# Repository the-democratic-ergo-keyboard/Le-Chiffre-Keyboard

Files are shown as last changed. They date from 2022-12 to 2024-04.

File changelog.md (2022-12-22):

Changelog:

Sadek Baroudi: 2022-12-15
-------------------------------
removed leftover decoupling capactiors, no longer needed
removed one of the shift registers
added two thumbs in the center
changed 2U to 1U and shifted keys inwards
redid routing so that front side is vertical, and backside is horizontal
fixed schematic
	* elite-c / nice nano
	* shift register
	* removed all the extra stuff that's no longer on the pcb
redid the switch matrix to use less cols to support the single shift register, and maximized gpio
added jlcpcb pcba support
other general cleanup...

Dasky: 2022-12-22
-------------------------------
add led power selection jumper raw/vcc
add led power switch circuit
added per key rgb
replaced ws2812b underglow with sk6803 mini-e
rotated all switches
rerouted pcb
add .gitignore
clean up backup files

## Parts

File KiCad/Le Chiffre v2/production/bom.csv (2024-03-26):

Designator | Footprint | Quantity | Value | LCSC Part #
D1, D10, D11, D12, D13, D14, D15, D16, D17, D18, D19, D2, D20, D21, D22, D23, D24, D25, D26, D27, D28, D29, D3, D30, D31, D32, D33, D34, D35, D36, D37, D4, D5, D6, D7, D8, D9 | D_SOD123 | 37 | 1N4148 | C909967
D38, D39, D40, D41, D42, D43, D44, D45, D46, D47, D48, D49, D50, D51, D52, D53, D54, D55, D56, D57, D58, D59, D60, D61, D62, D63, D64, D65, D66, D67, D68, D69, D70, D71, D72, D73, D74, D75, D76, D77, D78, D79, D80, D81, D82, D83, D84 | SK6803-MINI-E | 47 | SK6803_MINI-E | C5242955
H1 | TPSensorModule | 1 | MountingHole
J1 | PinHeader_1x06_P2.54mm_Vertical | 1 | Conn_01x06_Socket
J2 | PinSocket_1x04_P2.54mm_Vertical | 1 | Conn_01x04_Female
J3 | vik-keyboard-connector-horizontal | 1 | ~ | C479750
JP1 | SolderJumper-3_P1.3mm_Open_RoundedPad1.0x1.5mm | 1 | SolderJumper_3_Open
JP2 | SolderJumper-3_P1.3mm_Open_RoundedPad1.0x1.5mm | 1 | Jumper_3_Open
R7, R8 | R_0805 | 2 | 4.7k | C269746
SW1 | SW_SPST_TL3342 | 1 | SW_Push
SW10, SW11, SW12, SW13, SW14, SW15, SW16, SW17, SW18, SW19, SW2, SW20, SW21, SW22, SW23, SW24, SW25, SW26, SW27, SW28, SW29, SW3, SW30, SW31, SW32, SW33, SW34, SW35, SW37, SW38, SW39, SW4, SW5, SW6, SW7, SW8, SW9 | MX-Alps-Choc-1U-NoLED | 37 | SW_Push
SW36 | RotaryEncoder_Alps_EC12E-Switch_Vertical_H20mm_CircularMountingHoles | 1 | Rotary_Encoder_Switch
U1 | pro-micro-controller | 1 | pro-micro-controller
U2 | SOIC-16_3.9x9.9mm_P1.27mm | 1 | SN74HC595 | C94270

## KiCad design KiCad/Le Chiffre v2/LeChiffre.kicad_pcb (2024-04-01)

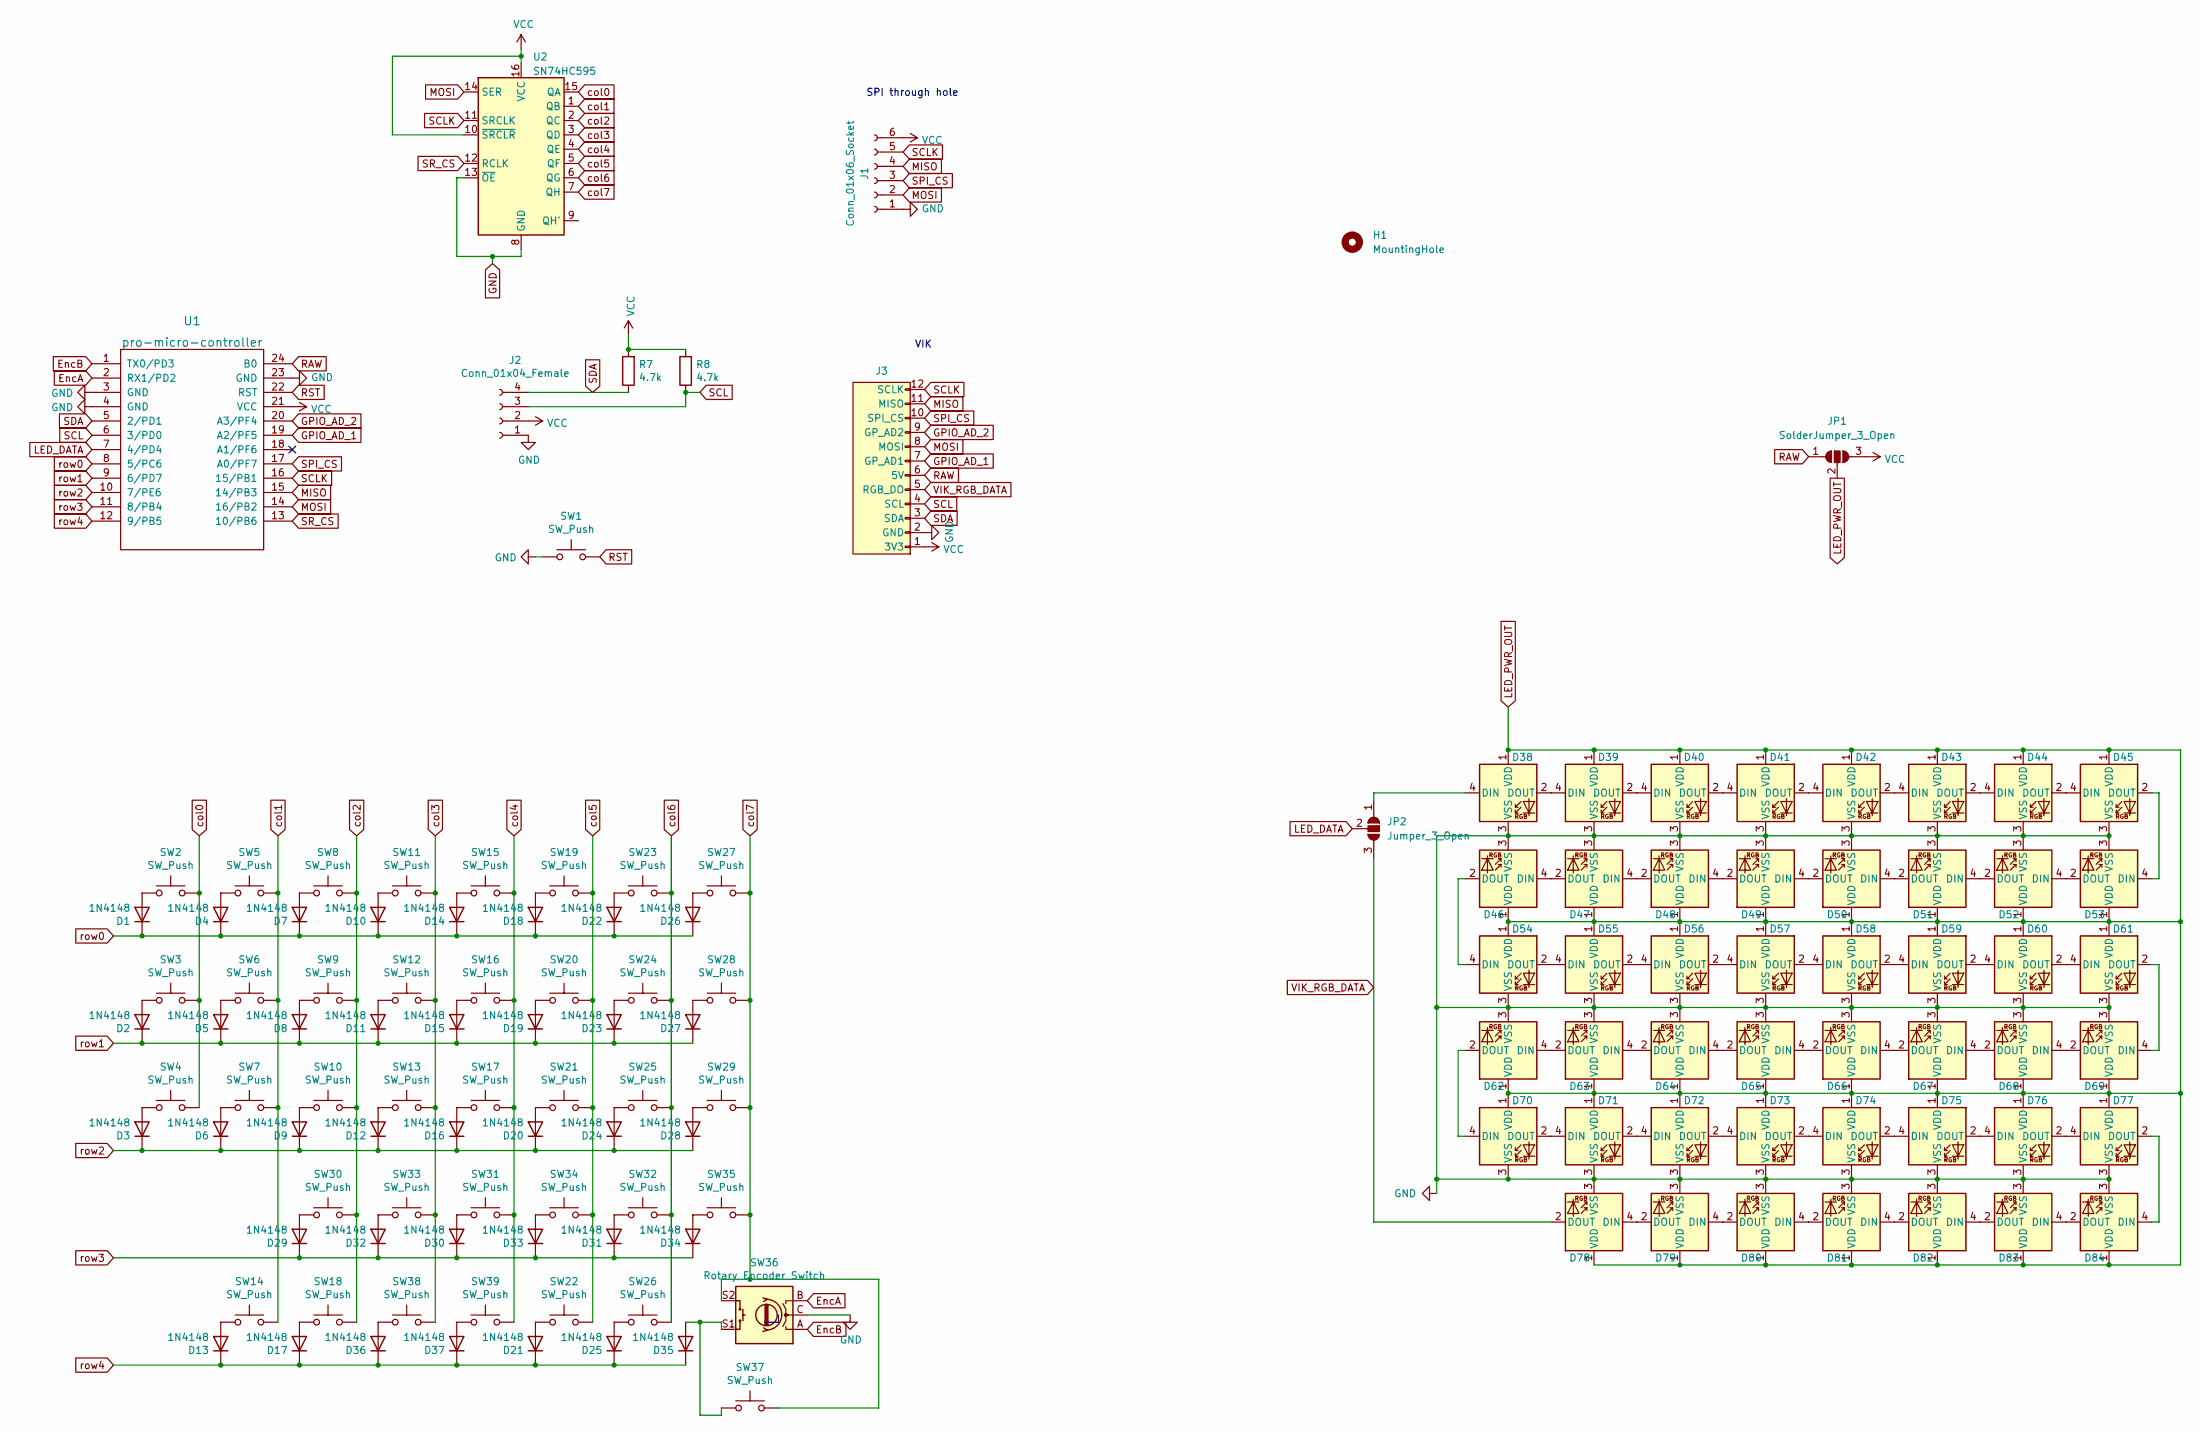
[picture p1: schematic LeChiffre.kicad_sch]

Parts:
D1, D2, D3, D4, D5, D6, D7, D8, D9, D10, D11, D12, D13, D14, D15, D16, D17, D18, D19, D20, D21, D22, D23, D24, D25, D26, D27, D28, D29, D30, D31, D32, D33, D34, D35, D36, D37: 1N4148; D_SOD123; LCSC C909967
D38, D39, D40, D41, D42, D43, D44, D45, D46, D47, D48, D49, D50, D51, D52, D53, D54, D55, D56, D57, D58, D59, D60, D61, D62, D63, D64, D65, D66, D67, D68, D69, D70, D71, D72, D73, D74, D75, D76, D77, D78, D79, D80, D81, D82, D83, D84: SK6803_MINI-E; SK6803-MINI-E; LCSC C5242955
H1: MountingHole; TPSensorModule
J1: Conn_01x06_Socket; PinHeader_1x06_P2.54mm_Vertical
J2: Conn_01x04_Female; PinSocket_1x04_P2.54mm_Vertical
J3: vik-keyboard-connector-horizontal; LCSC C479750
JP1: SolderJumper_3_Open; SolderJumper-3_P1.3mm_Open_RoundedPad1.0x1.5mm
JP2: Jumper_3_Open; SolderJumper-3_P1.3mm_Open_RoundedPad1.0x1.5mm
R7, R8: 4.7k; R_0805; LCSC C269746
SW1: SW_Push; SW_SPST_TL3342
SW2, SW3, SW4, SW5, SW6, SW7, SW8, SW9, SW10, SW11, SW12, SW13, SW14, SW15, SW16, SW17, SW18, SW19, SW20, SW21, SW22, SW23, SW24, SW25, SW26, SW27, SW28, SW29, SW30, SW31, SW32, SW33, SW34, SW35, SW37, SW38, SW39: SW_Push; MX-Alps-Choc-1U-NoLED
SW36: Rotary_Encoder_Switch; RotaryEncoder_Alps_EC12E-Switch_Vertical_H20mm_CircularMoun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
U1: pro-micro-controller
U2: SN74HC595; SOIC-16_3.9x9.9mm_P1.27mm; LCSC C94270

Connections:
EncA: SW36.B, U1.2 (RX1/PD2)
EncB: SW36.A, U1.1 (TX0/PD3)
GND: D38.3 (VSS), D39.3 (VSS), D40.3 (VSS), D41.3 (VSS), D42.3 (VSS), D43.3 (VSS), D44.3 (VSS), D45.3 (VSS), D46.3 (VSS), D47.3 (VSS), D48.3 (VSS), D49.3 (VSS), D50.3 (VSS), D51.3 (VSS), D52.3 (VSS), D53.3 (VSS), D54.3 (VSS), D55.3 (VSS), D56.3 (VSS), D57.3 (VSS), D58.3 (VSS), D59.3 (VSS), D60.3 (VSS), D61.3 (VSS), D62.3 (VSS), D63.3 (VSS), D64.3 (VSS), D65.3 (VSS), D66.3 (VSS), D67.3 (VSS), D68.3 (VSS), D69.3 (VSS), D70.3 (VSS), D71.3 (VSS), D72.3 (VSS), D73.3 (VSS), D74.3 (VSS), D75.3 (VSS), D76.3 (VSS), D77.3 (VSS), D78.3 (VSS), D79.3 (VSS), D80.3 (VSS), D81.3 (VSS), D82.3 (VSS), D83.3 (VSS), D84.3 (VSS), J1.1, J2.1, J3.2 (GND), SW1.1, SW36.C, U1.3 (GND), U1.4 (GND), U1.23 (GND), U2.8 (GND), U2.13 (~OE)
GPIO_AD_1: J3.7 (GP_AD1), U1.19 (A2/PF5)
GPIO_AD_2: J3.9 (GP_AD2), U1.20 (A3/PF4)
LED_DATA: JP2.2 (C), U1.7 (4/PD4)
LED_PWR_OUT: D38.1 (VDD), D39.1 (VDD), D40.1 (VDD), D41.1 (VDD), D42.1 (VDD), D43.1 (VDD), D44.1 (VDD), D45.1 (VDD), D46.1 (VDD), D47.1 (VDD), D48.1 (VDD), D49.1 (VDD), D50.1 (VDD), D51.1 (VDD), D52.1 (VDD), D53.1 (VDD), D54.1 (VDD), D55.1 (VDD), D56.1 (VDD), D57.1 (VDD), D58.1 (VDD), D59.1 (VDD), D60.1 (VDD), D61.1 (VDD), D62.1 (VDD), D63.1 (VDD), D64.1 (VDD), D65.1 (VDD), D66.1 (VDD), D67.1 (VDD), D68.1 (VDD), D69.1 (VDD), D70.1 (VDD), D71.1 (VDD), D72.1 (VDD), D73.1 (VDD), D74.1 (VDD), D75.1 (VDD), D76.1 (VDD), D77.1 (VDD), D78.1 (VDD), D79.1 (VDD), D80.1 (VDD), D81.1 (VDD), D82.1 (VDD), D83.1 (VDD), D84.1 (VDD), JP1.2 (C)
MISO: J1.4, J3.11 (MISO), U1.15 (14/PB3)
MOSI: J1.2, J3.8 (MOSI), U1.14 (16/PB2), U2.14 (SER)
unnamed: D1.2 (A), SW2.1
unnamed: D2.2 (A), SW3.1
unnamed: D3.2 (A), SW4.1
unnamed: D4.2 (A), SW5.1
unnamed: D5.2 (A), SW6.1
unnamed: D6.2 (A), SW7.1
unnamed: D7.2 (A), SW8.1
unnamed: D8.2 (A), SW9.1
unnamed: D9.2 (A), SW10.1
unnamed: D10.2 (A), SW11.1
unnamed: D11.2 (A), SW12.1
unnamed: D12.2 (A), SW13.1
unnamed: D13.2 (A), SW14.1
unnamed: D14.2 (A), SW15.1
unnamed: D15.2 (A), SW16.1
unnamed: D16.2 (A), SW17.1
unnamed: D17.2 (A), SW18.1
unnamed: D18.2 (A), SW19.1
unnamed: D19.2 (A), SW20.1
unnamed: D20.2 (A), SW21.1
unnamed: D21.2 (A), SW22.1
unnamed: D22.2 (A), SW23.1
unnamed: D23.2 (A), SW24.1
unnamed: D24.2 (A), SW25.1
unnamed: D25.2 (A), SW26.1
unnamed: D26.2 (A), SW27.1
unnamed: D27.2 (A), SW28.1
unnamed: D28.2 (A), SW29.1
unnamed: D29.2 (A), SW30.1
unnamed: D30.2 (A), SW31.1
unnamed: D31.2 (A), SW32.1
unnamed: D32.2 (A), SW33.1
unnamed: D33.2 (A), SW34.1
unnamed: D34.2 (A), SW35.1
unnamed: D35.2 (A), SW36.S1, SW37.1
unnamed: D36.2 (A), SW38.1
unnamed: D37.2 (A), SW39.1
unnamed: D38.4 (DIN), JP2.1 (A)
unnamed: D38.2 (DOUT), D39.4 (DIN)
unnamed: D39.2 (DOUT), D40.4 (DIN)
unnamed: D40.2 (DOUT), D41.4 (DIN)
unnamed: D41.2 (DOUT), D42.4 (DIN)
unnamed: D42.2 (DOUT), D43.4 (DIN)
unnamed: D43.2 (DOUT), D44.4 (DIN)
unnamed: D44.2 (DOUT), D45.4 (DIN)
unnamed: D45.2 (DOUT), D53.4 (DIN)
unnamed: D46.4 (DIN), D47.2 (DOUT)
unnamed: D46.2 (DOUT), D54.4 (DIN)
unnamed: D47.4 (DIN), D48.2 (DOUT)
unnamed: D48.4 (DIN), D49.2 (DOUT)
unnamed: D49.4 (DIN), D50.2 (DOUT)
unnamed: D50.4 (DIN), D51.2 (DOUT)
unnamed: D51.4 (DIN), D52.2 (DOUT)
unnamed: D52.4 (DIN), D53.2 (DOUT)
unnamed: D54.2 (DOUT), D55.4 (DIN)
unnamed: D55.2 (DOUT), D56.4 (DIN)
unnamed: D56.2 (DOUT), D57.4 (DIN)
unnamed: D57.2 (DOUT), D58.4 (DIN)
unnamed: D58.2 (DOUT), D59.4 (DIN)
unnamed: D59.2 (DOUT), D60.4 (DIN)
unnamed: D60.2 (DOUT), D61.4 (DIN)
unnamed: D61.2 (DOUT), D69.4 (DIN)
unnamed: D62.4 (DIN), D63.2 (DOUT)
unnamed: D62.2 (DOUT), D70.4 (DIN)
unnamed: D63.4 (DIN), D64.2 (DOUT)
unnamed: D64.4 (DIN), D65.2 (DOUT)
unnamed: D65.4 (DIN), D66.2 (DOUT)
unnamed: D66.4 (DIN), D67.2 (DOUT)
unnamed: D67.4 (DIN), D68.2 (DOUT)
unnamed: D68.4 (DIN), D69.2 (DOUT)
unnamed: D70.2 (DOUT), D71.4 (DIN)
unnamed: D71.2 (DOUT), D72.4 (DIN)
unnamed: D72.2 (DOUT), D73.4 (DIN)
unnamed: D73.2 (DOUT), D74.4 (DIN)
unnamed: D74.2 (DOUT), D75.4 (DIN)
unnamed: D75.2 (DOUT), D76.4 (DIN)
unnamed: D76.2 (DOUT), D77.4 (DIN)
unnamed: D77.2 (DOUT), D84.4 (DIN)
unnamed: D78.4 (DIN), D79.2 (DOUT)
unnamed: D79.4 (DIN), D80.2 (DOUT)
unnamed: D80.4 (DIN), D81.2 (DOUT)
unnamed: D81.4 (DIN), D82.2 (DOUT)
unnamed: D82.4 (DIN), D83.2 (DOUT)
unnamed: D83.4 (DIN), D84.2 (DOUT)
RAW: J3.6 (5V), JP1.1 (A), U1.24 (B0)
RST: SW1.2, U1.22 (RST)
SCL: J2.3, J3.4 (SCL), R8.1, U1.6 (3/PD0)
SCLK: J1.5, J3.12 (SCLK), U1.16 (15/PB1), U2.11 (SRCLK)
SDA: J2.4, J3.3 (SDA), R7.1, U1.5 (2/PD1)
SPI_CS: J1.3, J3.10 (SPI_CS), U1.17 (A0/PF7)
SR_CS: U1.13 (10/PB6), U2.12 (RCLK)
VCC: J1.6, J2.2, J3.1 (3V3), JP1.3 (B), R7.2, R8.2, U1.21 (VCC), U2.10 (~SRCLR), U2.16 (VCC)
VIK_RGB_DATA: D78.2 (DOUT), J3.5 (RGB_DO), JP2.3 (B)
col0: SW2.2, SW3.2, SW4.2, U2.15 (QA)
col1: SW5.2, SW6.2, SW7.2, SW14.2, U2.1 (QB)
col2: SW8.2, SW9.2, SW10.2, SW18.2, SW30.2, U2.2 (QC)
col3: SW11.2, SW12.2, SW13.2, SW33.2, SW38.2, U2.3 (QD)
col4: SW15.2, SW16.2, SW17.2, SW31.2, SW39.2, U2.4 (QE)
col5: SW19.2, SW20.2, SW21.2, SW22.2, SW34.2, U2.5 (QF)
col6: SW23.2, SW24.2, SW25.2, SW26.2, SW32.2, U2.6 (QG)
col7: SW27.2, SW28.2, SW29.2, SW35.2, SW36.S2, SW37.2, U2.7 (QH)
row0: D1.1 (K), D4.1 (K), D7.1 (K), D10.1 (K), D14.1 (K), D18.1 (K), D22.1 (K), D26.1 (K), U1.8 (5/PC6)
row1: D2.1 (K), D5.1 (K), D8.1 (K), D11.1 (K), D15.1 (K), D19.1 (K), D23.1 (K), D27.1 (K), U1.9 (6/PD7)
row2: D3.1 (K), D6.1 (K), D9.1 (K), D12.1 (K), D16.1 (K), D20.1 (K), D24.1 (K), D28.1 (K), U1.10 (7/PE6)
row3: D29.1 (K), D30.1 (K), D31.1 (K), D32.1 (K), D33.1 (K), D34.1 (K), U1.11 (8/PB4)
row4: D13.1 (K), D17.1 (K), D21.1 (K), D25.1 (K), D35.1 (K), D36.1 (K), D37.1 (K), U1.12 (9/PB5)

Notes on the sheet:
SPI through hole
VIK

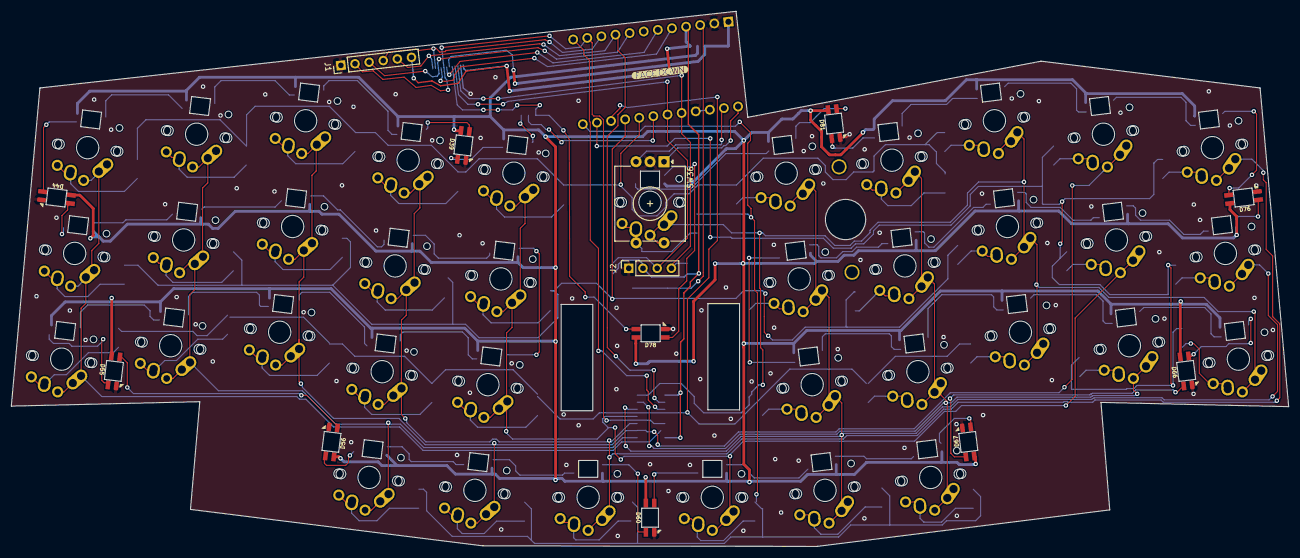
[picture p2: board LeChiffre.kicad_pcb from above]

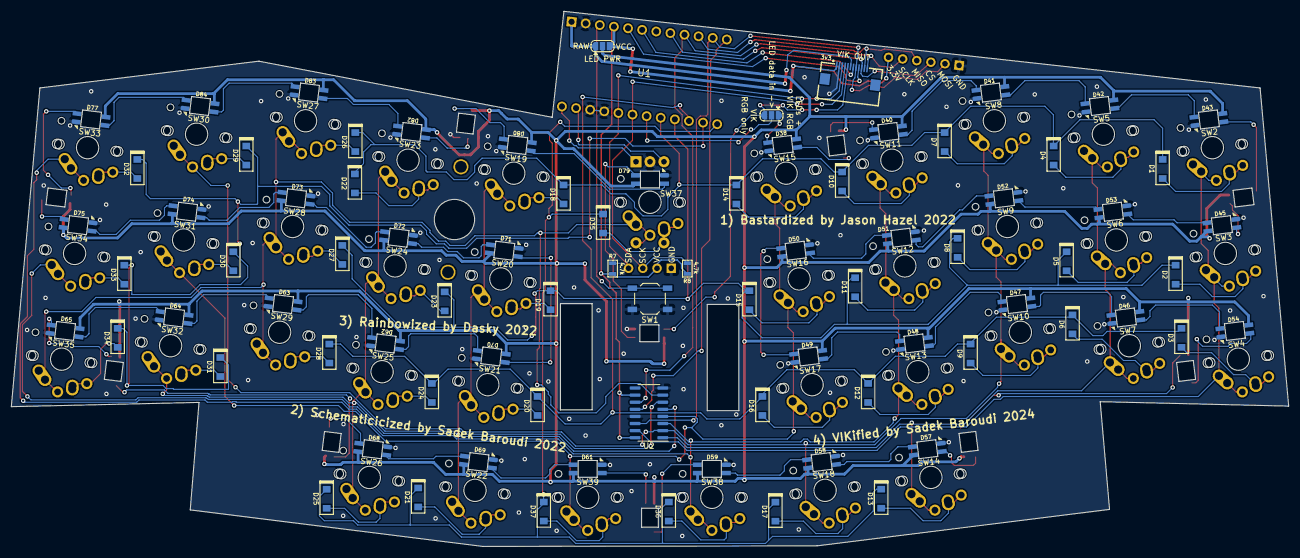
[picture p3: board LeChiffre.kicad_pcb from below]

Board: 2 copper layers, 228.4 x 95.7 mm, 134 parts (82 on the bottom side), 115 nets.

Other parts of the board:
kibuzzard-6397B74C: G***; kibuzzard-6397B74C

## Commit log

2022-12-14 swapped to mcu daughterboard for no good reason
    [LeChiffre.kicad_pcb]
2022-12-14 cleanup tracks and vias
    [LeChiffre.kicad_pcb]
2022-12-14 forgot to save
    [LeChiffre.kicad_pcb]
2022-12-16 Schematics, key additions, changed shift registers, rerouting, and more, see changelog.md
    [LeChiffre.kicad_sch, LeChiffre_Plate.kicad_pcb, bom.csv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]
2022-12-22 rainbow mode
    [LeChiffre.kicad_sch]
2022-12-22 Added PCBA for Dasky's changes
    [LeChiffre.kicad_sch, bom.csv, designators.csv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]
2024-02-28 added vik support, and extra spi through holes
    [LeChiffre-B_Cu.gbr, LeChiffre-B_Fab.gbr, LeChiffre-B_Mask.gbr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]
2024-03-01 led data no longer bridged by default, and fixed silk for vikification message
    [LeChiffre.kicad_pcb, LeChiffre.kicad_sch, bom.csv]
2024-03-04 added better VIK cable openings
    [LeChiffre.kicad_pcb]
2024-03-05 added trackpoint mounting support
    [LeChiffre.kicad_pcb, LeChiffre.kicad_sch, bom.csv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]
2024-04-01 fixed diode orientation to work with shift register
    [LeChiffre.kicad_pcb, LeChiffre.kicad_sch, positions.csv]
